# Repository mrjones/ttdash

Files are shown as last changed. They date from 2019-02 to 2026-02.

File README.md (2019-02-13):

# TrainTrack Dashboard

A NYC subway countdown clock for home.

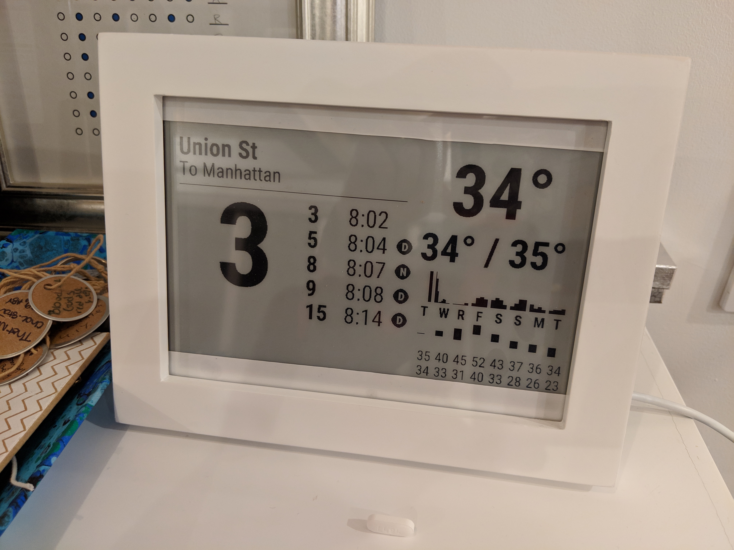
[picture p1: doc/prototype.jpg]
Prototype Image


* [Parts](https://github.com/mrjones/ttdash/blob/master/doc/parts.md)
* [Cross Compiling for ARM](https://github.com/mrjones/ttdash/blob/master/doc/cross-compiling.md)

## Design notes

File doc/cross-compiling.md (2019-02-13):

The rust compiler ran out of memory when I ran it directly on the Pi Zero.  One option is to compile on a different Pi (models other than the zero seem to have more ram). Another option is to compile it on a desktop/x86 computer and just copy the binary.  It's a little bit of a hassle, primarily because of an OpenSSL dependency.  However, it does work, and here are some rough notes on how I got it to go:

```
rustup target add arm-unknown-linux-gnueabihf
rustup target add armv7-unknown-linux-gnueabihf
```

Edit ~/.cargo/config to add:
```
[target.armv7-unknown-linux-gnueabihf]
linker = "arm-linux-gnueabihf-gcc"

[target.arm-unknown-linux-gnueabihf]
linker = "arm-linux-gnueabihf-gcc"
```

This helps us compile things for Raspberry Pi:
```
$ git clone https://github.com/raspberrypi/tools.git pitools
```

TTDash uses an HTTP library which depends on OpenSSL. So we have to download and compile OpenSSL for arm.  (Note that --cross-compile-prefix should point to the directory from the previous step.)
```
$ git clone https://github.com/openssl/openssl.git
$ cd openssl
$ git checkout --track origin/OpenSSL_1_1_1-stable
$ export INSTALL_DIR=~/arm/
$ ./Configure linux-generic32 shared --prefix=/home/mrjones/arm/ --openssldir=/home/mrjones/arm/openssl/ --cross-compile-prefix=~/src/pitools/arm-bcm2708/gcc-linaro-arm-linux-gnueabihf-raspbian-x64/bin/arm-linux-gnueabihf-
$ make depend && make && make install && make install
```

Now in the TTDash directory:
```
$ PATH=$PATH:/home/mrjones/src/pitools/arm-bcm2708/arm-linux-gnueabihf/bin/
$ export OPENSSL_INCLUDE_DIR=/home/mrjones/arm/include ; export OPENSSL_LIB_DIR=/home/mrjones/arm/lib ; cargo build --target arm-unknown-linux-gnueabihf
```

This was mostly inspired by:
[https://github.com/tiziano88/rust-raspberry-pi/blob/master/Dockerfile](https://github.com/tiziano88/rust-raspberry-pi/blob/master/Dockerfile)

For what it's worth [this StackOverflow answer](https://stackoverflow.com/questions/37375712/cross-compile-rust-openssl-for-raspberry-pi-2) also seemed promising, but I haven't tried it yet.

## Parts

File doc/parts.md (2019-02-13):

# Parts List

* [WaveShare 7.5 inch B&W e-paper display with HAT](https://www.amazon.com/gp/product/B075R4QY3L/ref=ppx_yo_dt_b_asin_title_o03__o00_s00?ie=UTF8&psc=1)
* [Raspberry Pi Zero](https://www.raspberrypi.org/products/raspberry-pi-zero/)
* [This random picture frame](https://www.amazon.com/gp/product/B06Y2HNDXQ/ref=ppx_yo_dt_b_asin_title_o01__o00_s00?ie=UTF8&psc=1)

The display and the frame aren't quite the same size, so I added a couple strips of white paper around the edges.

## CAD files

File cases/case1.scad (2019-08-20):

// TODO:
// 1. More space for cable, requires ~4mm below bottom of screen
// 2. Hold the screen in place better
// 3. Mount for raspi
//
// Maybe:
// - Bigger notch, so I don't have to clear out the debris?
// - It's a little transparent when the sun is behind it
// - Is angle best?
// - Maybe the slot should be on the sides instead of the bottom

module example_intersection()
{
  // Options for case
  thickness = 6;
  angle = 20;
  bottom_bezel = 20;
  main_bezel = 10;
  base_depth = 50;
  cable_notch_width = 30;

  // Physical params of display
  screen_width = 163;
  screen_height = 97;
  inset = 4;
  bottom_inset = 10;
  inset_thickness = 2;

  // Computed params
  frame_outside_width = screen_width + 2 * main_bezel;
  frame_outside_height = screen_height + bottom_bezel + main_bezel;

  leftover_inset = main_bezel - inset;
  leftover_bottom_inset = bottom_bezel - bottom_inset;

  // Increasing X: Left to right, looking straight on
  // Increasing Y: Down to up, looking straight on
  // Increazing Z: Front to back, looking straight on

  rotate([0,0,0]) {
    // Main frame
    difference() {
      rotate([angle, 0, 0]) {
        difference() {
          union() {
            difference() {
              // Main housing
              cube([frame_outside_width, frame_outside_height, thickness], center=false);

              // Punch a hole all the way through for visible part of the screen
              translate([main_bezel, bottom_bezel,0]) {
                cube([screen_width, screen_height, thickness], center= false);
              };

              // Slightly larger inset a bit around edges
              // Leaves inset_thickness remaining
              translate([leftover_inset, leftover_bottom_inset, inset_thickness]) {
                cube([screen_width + 2 * inset, frame_outside_height - leftover_bottom_inset, thickness-inset_thickness], center = false);
              };
            };

            translate([0, 0, thickness - inset_thickness]) {
              difference() {
                cube([frame_outside_width, frame_outside_height, inset_thickness], center=false);
                translate([main_bezel,bottom_bezel,0]) {
                  cube([screen_width, screen_height + main_bezel, inset_thickness], center=false);
                };
              };
            };

            // Add a back for the little slot
//            translate([0, leftover_bottom_inset, thickness - inset_thickness]) {
//              cube([frame_outside_width, bottom_inset, inset_thickness], center = false);
//            };

          };

          // Remove a notch for the cable:
          translate([(frame_outside_width - cable_notch_width) / 2, 0, inset_thickness]) {
            cube([cable_notch_width, bottom_bezel, thickness - inset_thickness], center = false);
          };
        };
      };


      // strip the lip off the bottom:
      void_height = 10;
      void_depth = 40;
      translate([0, void_height * -1, void_depth / 2 * -1]) {
        cube([frame_outside_width, void_height, void_depth], center=false);
      }
    }

    // Base
    difference() {
      cube([frame_outside_width, thickness, base_depth]);

      translate([thickness, 0, 0]) {
        cube([frame_outside_width - thickness * 2, thickness, base_depth]);
      }

      // strip the lip off the front:
      translate([0, 0, thickness * -1]) {
        rotate([angle, 0, 0]) {
          cube([frame_outside_width, frame_outside_height, thickness], center=false);
        }
      }
    }
  }
}

example_intersection();

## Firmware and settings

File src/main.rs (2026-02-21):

// sudo apt-get install fonts-roboto libssl-dev
#[macro_use] extern crate anyhow;
extern crate chrono;
extern crate chrono_tz;
extern crate flexi_logger;
extern crate getopts;
extern crate hex;
extern crate image;
extern crate imageproc;
#[macro_use] extern crate log;
extern crate md5;
extern crate nix;
extern crate pretty_bytes;
extern crate prost;
extern crate querystring;
extern crate reqwest;
extern crate rppal;
extern crate rusttype;
#[macro_use] extern crate serde_derive;
#[macro_use] extern crate serde_with;
#[macro_use] extern crate time;
extern crate tiny_http;

mod bustime;
mod debug;
mod display;
mod drawing;
mod purpleair;
mod result;
mod subway;
mod update;
mod weather;


pub mod webclient_api {
    include!(concat!(env!("OUT_DIR"), "/webclient_api.rs"));
}


struct SleepSchedule {
    start_hour: u32,  // Hour to start sleeping (e.g. 22 for 10pm), Eastern time
    end_hour: u32,    // Hour to stop sleeping (e.g. 6 for 6am), Eastern time
}

impl SleepSchedule {
    fn is_sleep_time(&self, now: &chrono::DateTime<chrono::Utc>) -> bool {
        use chrono::Timelike;
        let eastern: chrono::DateTime<chrono_tz::Tz> = now.with_timezone(&chrono_tz::US::Eastern);
        let hour = eastern.hour();
        if self.start_hour > self.end_hour {
            // Crosses midnight: e.g. 22-6 means sleep from 22:00 to 05:59
            hour >= self.start_hour || hour < self.end_hour
        } else {
            hour >= self.start_hour && hour < self.end_hour
        }
    }
}

struct TTDash<'a> {
    weather_display: Option<weather::WeatherDisplay>,
    forecast_timestamp: chrono::DateTime<chrono::Utc>,
    air_quality: Option<purpleair::AirQuality>,
    air_quality_timestamp: chrono::DateTime<chrono::Utc>,
    bus_time_data: Option<bustime::BusTimeDisplayData>,
    styles: drawing::Styles<'a>,
    last_redraw: Option<chrono::DateTime<chrono::Utc>>,
    is_sleeping: bool,
}

impl<'a> TTDash<'a> {
    fn new() -> TTDash<'a> {
        // ln

        let font = include_bytes!("/usr/share/fonts/truetype/roboto/unhinted/RobotoCondensed-Regular.ttf");
        let font = rusttype::Font::try_from_bytes(font).unwrap();

        let font_black = include_bytes!("/usr/share/fonts/truetype/roboto/unhinted/RobotoCondensed-Bold.ttf");
        let font_black = rusttype::Font::try_from_bytes(font_black).unwrap();

        let font_bold = include_bytes!("/usr/share/fonts/truetype/roboto/unhinted/RobotoCondensed-Bold.ttf");
        let font_bold = rusttype::Font::try_from_bytes(font_bold).unwrap();

        return TTDash {
            weather_display: None,
            forecast_timestamp: chrono::Utc::now(),
            air_quality: None,
            air_quality_timestamp: chrono::Utc::now(),
            bus_time_data: None,
            styles: drawing::Styles{
                font_black: font_black,
                font_bold: font_bold,
                font: font,
                color_black: image::Luma([0u8; 1]),
                color_dark_gray: image::Luma([128u8; 1]),
                color_light_gray: image::Luma([192u8; 1]),
                color_white: image::Luma([255u8; 1]),
            },
            last_redraw: None,
            is_sleeping: false,
        }
    }

    fn update_air_quality(&mut self, creds: &purpleair::Credentials, now: &chrono::DateTime<chrono::Utc>) -> result::TTDashResult<()> {
        self.air_quality = Some(purpleair::get_air_quality(creds)?);
        self.air_quality_timestamp = *now;

        return Ok(());
    }

    fn update_weather(&mut self, now: &chrono::DateTime<chrono::Utc>) -> result::TTDashResult<()> {
        self.weather_display = Some(weather::get_weather_display(now.timestamp())?);
        self.forecast_timestamp = *now;

        return Ok(());
    }

    fn one_iteration(&mut self, display: bool, png_out: Option<&str>, prev_processed_data: &subway::ProcessedData, auto_update: bool, update_track: &str, panel_version: display::PanelVersion, purpleair_creds: Option<&purpleair::Credentials>, mta_bustime_creds: Option<&String>) -> result::TTDashResult<Option<subway::ProcessedData>> {
        if auto_update {
            match update::binary_update_available(update_track) {
                Some(target) => {
                    info!("Upgrade available to version {}.", target.version);
                    let argv0 = std::env::args().nth(0).expect("argv0");
                    let argv: Vec<String> = std::env::args().collect();
                    match update::upgrade_to(&target, &argv0, &argv) {
                        Err(err) => error!("Upgrade error: {:?}", err),
                        _ => {},
                    }
                },
                None => {
                    debug!("No update available");
                },
            }
        }


        let processed_data = subway::fetch_and_process_data()?;

        // TODO(mrjones): Make this async or something?
        // TODO(mrjones): Don't fetch every time
        let now = chrono::Utc::now();
        if self.weather_display.is_none() || (now.timestamp() - self.forecast_timestamp.timestamp() > 60 * 30) {
            match self.update_weather(&now) {
                Ok(_) => {},
                Err(err) => error!("Error updating weather: {:?}", err),
            }
        }

        if purpleair_creds.is_some() {
            if self.air_quality.is_none() || (now.timestamp() - self.air_quality_timestamp.timestamp() > 60) {
                match self.update_air_quality(purpleair_creds.unwrap(), &now) {
                    Ok(_) => { info!("AQ: {:?}", self.air_quality); },
                    Err(err) => { error!("Error updating air quality: {:?}", err); },
                }
            }

        }

        if mta_bustime_creds.is_some() {
            let bustimes = bustime::get_garfield_bus_arrivals(mta_bustime_creds.unwrap().as_ref());
            debug!("FINAL BUSTIMES: {:?}", bustimes);

            match bustimes {
                Ok(bustimes) => {
                    let now = time::OffsetDateTime::now_utc();

                    let ts_to_wait_minutes = |ts: &time::OffsetDateTime| {
                        let delta = ts.clone() - now;
                        return delta.whole_minutes();
                    };

                    let uptown_waits: Vec<i64> = bustimes.uptown_timestamps.iter().map(ts_to_wait_minutes).collect();
                    let downtown_waits: Vec<i64> = bustimes.downtown_timestamps.iter().map(ts_to_wait_minutes).collect();
                    debug!("UPTOWN WAITS: {:?}", uptown_waits);
                    debug!("DOWNTOWN WAITS: {:?}", downtown_waits);

                    self.bus_time_data = Some(bustime::BusTimeDisplayData{
                        uptown_waits,
                        downtown_waits,
                        timestamp: time::OffsetDateTime::now_utc(),
                    });
                },
                Err(err) => error!("Error getting bustimes: {}", err),
            }
        }

        let mut needs_redraw = false;

        let data_went_back_in_time = processed_data.data_timestamp < prev_processed_data.data_timestamp;
        if data_went_back_in_time {
            debug!("Ignoring data ({}) that's older than what's already displayed ({}).",
                  processed_data.data_timestamp,
                  prev_processed_data.data_timestamp);
        }

        if prev_processed_data.big_countdown != processed_data.big_countdown &&
            !data_went_back_in_time {
            debug!("Updating bignum {:?} -> {:?}",
                     prev_processed_data.big_countdown,
                     processed_data.big_countdown);
            needs_redraw = true;
        } else if self.last_redraw.is_none() {
            // Probably never happens in practice?
            info!("Drawing for the first time.");
            needs_redraw = true;
        } else if self.last_redraw.is_some() {
            let seconds_since_redraw = now.timestamp() - self.last_redraw.unwrap().timestamp();
            needs_redraw = seconds_since_redraw > 60 * 30;
            if needs_redraw {
                info!("Redrawing since it's been too long.");
            }
        }

        if needs_redraw {
            let imgbuf = drawing::generate_image(
                &processed_data,
                self.weather_display.as_ref(),
                self.air_quality.as_ref(),
                self.bus_time_data.as_ref(),
                update::local_version().ok().map(|v| v.to_string()),
                &self.styles,
                panel_version.width(),
                panel_version.height())?;

            if png_out.is_some() {
                let _ = imgbuf.save(png_out.unwrap())?;
            }

            if display {
                display::setup_and_display_image(&imgbuf, panel_version)?;
            }
            self.last_redraw = Some(now);
            return Ok(Some(processed_data));
        } else {
            debug!("Not refreshing.");
            return Ok(None)
        }
    }
}

fn short_level(level: log::Level) -> String {
    return match level {
        log::Level::Error => "E".to_string(),
        log::Level::Warn => "W".to_string(),
        log::Level::Info => "I".to_string(),
        log::Level::Debug => "D".to_string(),
        _ => level.to_string(),
    };
}

fn format_log(
    w: &mut dyn std::io::Write,
    now: &mut flexi_logger::DeferredNow,
    record: &log::Record,
) -> Result<(), std::io::Error> {
    write!(
        w,
        "[{}{} {}:{:<4}] {}",
        short_level(record.level()),
        now.now().format("%Y%m%d %H:%M:%S.%3f"),
        record.file().unwrap_or("<unnamed>"),
        record.line().unwrap_or(0),
        &record.args()
    )
}

fn main() {
    flexi_logger::Logger::try_with_env_or_str("info")
        .unwrap()
        .format(format_log)
        .log_to_file(flexi_logger::FileSpec::default().use_timestamp(true))
        .append()
        .duplicate_to_stderr(flexi_logger::Duplicate::Info)
        .rotate(
            flexi_logger::Criterion::Size(1 * 1024 * 1024),
            flexi_logger::Naming::Numbers,
            flexi_logger::Cleanup::KeepLogFiles(100))
        .print_message()
        .start()
        .unwrap();

    let args: Vec<String> = std::env::args().collect();
    info!(" - - - - - - - - - - - - - ");
    info!("Command Line: {:?}", args);
    match update::local_version() {
        Ok(version) => {
            info!("TTDash version {}", version);
        },
        _ => {},
    }

    let mut opts = getopts::Options::new();
    opts.optflag("d", "skip-display", "display to the epd device");
    opts.optflag("o", "one-shot", "keep the display up to date");
    opts.optopt("i", "save-image", "Where to put a png.", "FILENAME");
    opts.optopt("p", "debug-port", "Port to run a debug server on.", "PORT");
    opts.optflag("u", "auto-update", "Run the auto-updater.");
    opts.optopt("", "update-track", "Update track to follow (e.g. arm, arm64).", "TRACK");
    opts.optopt("", "panel-version", "E-paper panel version: v1 (640x384) or v2 (800x480).", "VERSION");

    opts.optopt("", "purpleair-credentials-file", "Name of a file containing JSON {key: xx, id: xxx} value with purpleair credentials.", "FILE");

    opts.optopt("", "mta-bustime-credentials-file", "Name of a file containing the MTA bustime API key", "FILE");

    opts.optopt("", "sleep-start", "Hour (0-23, Eastern) to start sleeping the display (e.g. 22 for 10pm).", "HOUR");
    opts.optopt("", "sleep-end", "Hour (0-23, Eastern) to stop sleeping the display (e.g. 6 for 6am).", "HOUR");

    let matches = opts.parse(&args[1..]).expect("parse opts");

    let display = !matches.opt_present("skip-display");
    let one_shot = matches.opt_present("one-shot");
    let debug_port = matches.opt_str("debug-port");
    let auto_update = matches.opt_present("auto-update");
    let update_track: String = matches.opt_str("update-track").unwrap_or("arm64".to_string());
    let panel_version = match matches.opt_str("panel-version").as_deref() {
        Some("v1") => display::PanelVersion::V1,
        Some("v2") => display::PanelVersion::V2,
        Some(other) => panic!("Unknown panel version '{}'. Use 'v1' or 'v2'.", other),
        None => display::PanelVersion::V2,
    };
    let local_png: Option<String> = matches.opt_str("save-image");
    let purpleair_creds: Option<purpleair::Credentials> =
        matches.opt_str("purpleair-credentials-file").map(
            |file| purpleair::credentials_from_file(file)
                .expect("while reading purpleair-credentials-file"));
    let mta_bustime_creds: Option<String> =
        matches.opt_str("mta-bustime-credentials-file").map(
            |file| std::fs::read_to_string(file)
                .expect("while reading purpleair-credentials-file"));

    let sleep_schedule: Option<SleepSchedule> = match (matches.opt_str("sleep-start"), matches.opt_str("sleep-end")) {
        (Some(start), Some(end)) => {
            let start_hour: u32 = start.parse().expect("sleep-start must be a number 0-23");
            let end_hour: u32 = end.parse().expect("sleep-end must be a number 0-23");
            assert!(start_hour < 24, "sleep-start must be 0-23");
            assert!(end_hour < 24, "sleep-end must be 0-23");
            Some(SleepSchedule { start_hour, end_hour })
        },
        (None, None) => None,
        _ => panic!("Must specify both --sleep-start and --sleep-end, or neither."),
    };

    info!("Running with config: display={} one-shot={} debug-port={:?} auto-update={} update-track={} local-png={:?}, purpleair-credentials={:?} mta-bustime-credentials={:?} sleep={:?}", display, one_shot, debug_port, auto_update, update_track, local_png, purpleair_creds, mta_bustime_creds, sleep_schedule.as_ref().map(|s| format!("{}-{}", s.start_hour, s.end_hour)));

    let mut prev_processed_data = subway::ProcessedData::empty();
    let mut ttdash = TTDash::new();

    match debug_port {
        Some(port) => {
            let local_png = local_png.clone();
            std::thread::spawn(move || { debug::run_debug_server(&port, local_png); });
        },
        None => {},
    }

    if auto_update {
        assert!(update::updater_configured());
    }

    loop {
        let now = chrono::Utc::now();
        let should_sleep = sleep_schedule.as_ref().map_or(false, |s| s.is_sleep_time(&now));

        if should_sleep {
            // Refresh weather/air quality data if stale
            if ttdash.weather_display.is_none() || (now.timestamp() - ttdash.forecast_timestamp.timestamp() > 60 * 30) {
                match ttdash.update_weather(&now) {
                    Ok(_) => {},
                    Err(err) => error!("Error updating weather in sleep mode: {:?}", err),
                }
            }
            if let Some(creds) = purpleair_creds.as_ref() {
                if ttdash.air_quality.is_none() || (now.timestamp() - ttdash.air_quality_timestamp.timestamp() > 60) {
                    match ttdash.update_air_quality(creds, &now) {
                        Ok(_) => {},
                        Err(err) => error!("Error updating air quality in sleep mode: {:?}", err),
                    }
                }
            }

            // Redraw on first sleep iteration, or once per hour
            let needs_redraw = if !ttdash.is_sleeping {
                info!("Entering sleep mode.");
                true
            } else if let Some(last) = ttdash.last_redraw {
                now.timestamp() - last.timestamp() > 60 * 60
            } else {
                true
            };

            if needs_redraw {
                match drawing::generate_sleep_image(
                    ttdash.weather_display.as_ref(),
                    ttdash.air_quality.as_ref(),
                    &ttdash.styles,
                    panel_version.width(), panel_version.height()) {
                    Ok(imgbuf) => {
                        if let Some(ref png_path) = local_png {
                            let _ = imgbuf.save(png_path);
                        }
                        if display {
                            match display::setup_and_display_image(&imgbuf, panel_version) {
                                Err(err) => error!("Error displaying sleep image: {}", err),
                                Ok(_) => {},
                            }
                        }
                        ttdash.last_redraw = Some(now);
                    },
                    Err(err) => error!("Error generating sleep image: {}", err),
                }
            }
            ttdash.is_sleeping = true;
        } else {
            if ttdash.is_sleeping {
                info!("Waking up from sleep mode.");
                ttdash.is_sleeping = false;
                ttdash.last_redraw = None;  // Force a redraw on wake
            }

            match ttdash.one_iteration(display, local_png.as_ref().map(String::as_ref), &prev_processed_data, auto_update, &update_track, panel_version, purpleair_creds.as_ref(), mta_bustime_creds.as_ref()) {
                Err(err) => error!("{}", err),
                Ok(processed_data) => {
                    if let Some(processed_data) = processed_data {
                        prev_processed_data = processed_data;
                    }
                }
            }
        }

        if one_shot {
            break;
        }

        let sleep_secs = if ttdash.is_sleeping { 60 } else { 5 };
        std::thread::sleep(std::time::Duration::from_secs(sleep_secs));
    }
}

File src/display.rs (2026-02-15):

extern crate image;
extern crate rppal;
extern crate std;
extern crate time;

use rppal::gpio::{Gpio, Level, InputPin, OutputPin};
use rppal::spi::{Spi};

use crate::result;

const RST_PIN : u8 = 17;
const DC_PIN : u8 = 25;
const _CS_PIN : u8 = 8;
const BUSY_PIN : u8 = 24;
const PWR_PIN : u8 = 18;

#[derive(Clone, Copy, PartialEq)]
pub enum PanelVersion {
    V1,  // 640x384, 4-bit grayscale
    V2,  // 800x480, 1-bit
}

impl PanelVersion {
    pub fn width(&self) -> u32 {
        match self {
            PanelVersion::V1 => 640,
            PanelVersion::V2 => 800,
        }
    }

    pub fn height(&self) -> u32 {
        match self {
            PanelVersion::V1 => 384,
            PanelVersion::V2 => 480,
        }
    }
}

pub fn setup_and_display_image(image: &image::GrayImage, panel: PanelVersion) -> result::TTDashResult<()>{
    let mut gpio = rppal::gpio::Gpio::new()?;
    let mut dc_pin = gpio.get(DC_PIN).expect("get dc pin").into_output();
    let busy_pin = gpio.get(BUSY_PIN).expect("get busy pin").into_input();

    // Don't forget to enable SPI with sudo raspi-config
    let mut spi = rppal::spi::Spi::new(
        rppal::spi::Bus::Spi0,
        rppal::spi::SlaveSelect::Ss0,
        2000000,
        rppal::spi::Mode::Mode0)?;

    if panel == PanelVersion::V2 {
        let mut pwr_pin = gpio.get(PWR_PIN).expect("get pwr pin").into_output();
        pwr_pin.set_reset_on_drop(false);
        pwr_pin.set_high();
        std::thread::sleep(std::time::Duration::from_millis(100));
    }

    init_display(&mut gpio, &mut spi, &mut dc_pin, &busy_pin, panel);
    display_image(&mut dc_pin, &busy_pin, &mut spi, image, panel);

    return Ok(());
}

fn send_command(dc_pin: &mut OutputPin, spi: &mut Spi, command: u8) {
    dc_pin.set_low();
    let v = vec![command];
    let bytes = spi.write(&v).expect("spi.write");
    assert_eq!(bytes, 1);
}

fn send_data(dc_pin: &mut OutputPin, spi: &mut Spi, data: u8) {
    dc_pin.set_high();
    let v = vec![data];
    let bytes = spi.write(&v).expect("spi.write");
    assert_eq!(bytes, 1);
}

fn send_data_bulk(dc_pin: &mut OutputPin, spi: &mut Spi, data: &[u8]) {
    dc_pin.set_high();
    for chunk in data.chunks(4096) {
        spi.write(chunk).expect("spi.write bulk");
    }
}

fn wait_until_idle_v1(busy_pin: &InputPin, timeout: time::Duration) {
    let deadline = time::Instant::now() + timeout;
    loop {
        if busy_pin.read() == Level::Low {
            return;
        }
        if time::Instant::now() > deadline {
            warn!("wait_until_idle timeout ({}) expired.", timeout);
            return;
        }
        std::thread::sleep(std::time::Duration::from_millis(100));
    }
}

fn wait_until_idle_v2(dc_pin: &mut OutputPin, spi: &mut Spi, busy_pin: &InputPin, timeout: time::Duration) {
    let deadline = time::Instant::now() + timeout;
    loop {
        send_command(dc_pin, spi, 0x71);
        if busy_pin.read() == Level::High {
            return;
        }
        if time::Instant::now() > deadline {
            warn!("wait_until_idle timeout ({}) expired.", timeout);
            return;
        }
        std::thread::sleep(std::time::Duration::from_millis(50));
    }
}

fn init_display(gpio: &mut Gpio, spi: &mut Spi, dc_pin: &mut OutputPin, busy_pin: &InputPin, panel: PanelVersion) {
    let mut rst_pin = gpio.get(RST_PIN).expect("get rst pin").into_output();

    match panel {
        PanelVersion::V1 => {
            rst_pin.set_low();
            std::thread::sleep(std::time::Duration::from_millis(200));
            rst_pin.set_high();
            std::thread::sleep(std::time::Duration::from_millis(200));

            send_command(dc_pin, spi, 0x01); // POWER_SETTING
            send_data(dc_pin, spi, 0x37);
            send_data(dc_pin, spi, 0x00);

            send_command(dc_pin, spi, 0x00); // PANEL_SETTING
            send_data(dc_pin, spi, 0xCF);
            send_data(dc_pin, spi, 0x08);

            send_command(dc_pin, spi, 0x06); // BOOSTER_SOFT_START
            send_data(dc_pin, spi, 0xc7);
            send_data(dc_pin, spi, 0xcc);
            send_data(dc_pin, spi, 0x28);

            send_command(dc_pin, spi, 0x04); // POWER_ON
            wait_until_idle_v1(&busy_pin, time::Duration::minutes(3));

            send_command(dc_pin, spi, 0x30); // PLL_CONTROL
            send_data(dc_pin, spi, 0x3c);

            send_command(dc_pin, spi, 0x41); // TEMPERATURE_CALIBRATION
            send_data(dc_pin, spi, 0x00);

            send_command(dc_pin, spi, 0x50); // VCOM_AND_DATA_INTERVAL_SETTING
            send_data(dc_pin, spi, 0x77);

            send_command(dc_pin, spi, 0x60); // TCON_SETTING
            send_data(dc_pin, spi, 0x22);

            send_command(dc_pin, spi, 0x61); // TCON_RESOLUTION
            send_data(dc_pin, spi, 0x02);    // source 640
            send_data(dc_pin, spi, 0x80);
            send_data(dc_pin, spi, 0x01);    // gate 384
            send_data(dc_pin, spi, 0x80);

            send_command(dc_pin, spi, 0x82); // VCM_DC_SETTING
            send_data(dc_pin, spi, 0x1E);

            send_command(dc_pin, spi, 0xe5); // FLASH MODE
            send_data(dc_pin, spi, 0x03);

            send_command(dc_pin, spi, 0x10); // DATA_START_TRANSMISSION
        },
        PanelVersion::V2 => {
            rst_pin.set_high();
            std::thread::sleep(std::time::Duration::from_millis(20));
            rst_pin.set_low();
            std::thread::sleep(std::time::Duration::from_millis(2));
            rst_pin.set_high();
            std::thread::sleep(std::time::Duration::from_millis(20));

            send_command(dc_pin, spi, 0x06); // BOOSTER_SOFT_START
            send_data(dc_pin, spi, 0x17);
            send_data(dc_pin, spi, 0x17);
            send_data(dc_pin, spi, 0x28);
            send_data(dc_pin, spi, 0x17);

            send_command(dc_pin, spi, 0x01); // POWER_SETTING
            send_data(dc_pin, spi, 0x07);
            send_data(dc_pin, spi, 0x07);
            send_data(dc_pin, spi, 0x28);
            send_data(dc_pin, spi, 0x17);

            send_command(dc_pin, spi, 0x04); // POWER_ON
            std::thread::sleep(std::time::Duration::from_millis(100));
            wait_until_idle_v2(dc_pin, spi, busy_pin, time::Duration::minutes(3));

            send_command(dc_pin, spi, 0x00); // PANEL_SETTING
            send_data(dc_pin, spi, 0x1F);

            send_command(dc_pin, spi, 0x61); // RESOLUTION
            send_data(dc_pin, spi, 0x03);    // source 800
            send_data(dc_pin, spi, 0x20);
            send_data(dc_pin, spi, 0x01);    // gate 480
            send_data(dc_pin, spi, 0xE0);

            send_command(dc_pin, spi, 0x15);
            send_data(dc_pin, spi, 0x00);

            send_command(dc_pin, spi, 0x50); // VCOM
            send_data(dc_pin, spi, 0x10);
            send_data(dc_pin, spi, 0x07);

            send_command(dc_pin, spi, 0x60); // TCON_SETTING
            send_data(dc_pin, spi, 0x22);
        },
    }
}
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

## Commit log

2018-10-27 flip bignum and list
    [main.rs]
2018-10-27 make image path a flag, and redesign a bit
    [main.rs]
2018-10-28 recover better from some errors
    [main.rs, result.rs]
2018-11-04 Condensed font for temperatures
2018-11-04 don't crash on JSON parse errors
    [result.rs]
2018-11-04 better handling of weather errors
    [main.rs]
2018-11-05 fix gray rendering to display
    [main.rs]
2018-12-25 handle multi-day stretches of precip_prob correctly
    [main.rs]
2018-12-26 show temperatures with precip chart
2018-12-28 slightly less awful code for temperature bars
2018-12-28 add groundwork for a debug http server
2019-05-27 fixed display.rs, drawing.rs still broken
    [display.rs]
2019-06-01 Fix double-initialization of some pins
    [display.rs]
2019-06-24 download and replace binary
    [main.rs]
2019-07-21 Lay some groundwork for the release script to have multiple tracks
2019-08-08 Prototype case
    [case1.scad]
2019-08-13 make cable notch go all the way down
    [case1.scad]
2019-08-19 don't go back in time with data
    [case1.scad]
2019-08-20 split bottom bezel param
    [case1.scad]
2019-08-20 debug logging server
    [case1.scad]
2019-08-26 add dyn a couple places
2019-08-27 Replace rust-protobuf with prost
    [main.rs, result.rs]
2020-01-16 Fetch current KNYC weather
2020-02-09 Use different source for current temperature. The old one hasn't updated in a few days?
2021-10-17 cargo update and fixing result api breakages
    [display.rs, main.rs, result.rs]
2021-11-27 Improve logging and errors in weather.rs
    [main.rs, result.rs]
2022-09-24 cargo update, and resulting fixes to get it compiling again
    [main.rs]
2023-07-25 cargo update and replaced simple_server with tiny_http
    [main.rs]
2026-02-14 Add aarch64 cross-compilation support for Pi Zero 2W
    The Pi Zero 2W runs 64-bit ARM, so the old arm-unknown-linux-gnueabihf
    target no longer works. This adds:
    - .cargo/config.toml with aarch64 linker config
    - build-arm64.sh and build-release-arm64.sh build scripts
    - --update-track flag to select the auto-updater track (defaults to arm64)
    - Updated time crate to fix Rust 1.80+ compatibility
    [main.rs]
2026-02-14 Add display_test binary for debugging e-paper panel communication
    Standalone test binary that exercises GPIO, SPI, and the V2 panel
    init sequence step-by-step with diagnostic output.
2026-02-14 Support V2 e-paper panel (800x480) for Pi Zero 2W migration
    The new Waveshare 7.5" V2 panel has a completely different protocol:
    - 800x480 resolution (was 640x384)
    - Requires PWR pin (GPIO 18) to be driven high
    - Different init register values and command ordering
    - Busy pin needs cmd 0x71 before reading
    - 1-bit pixel data sent via two commands (0x10 + 0x13)
    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
